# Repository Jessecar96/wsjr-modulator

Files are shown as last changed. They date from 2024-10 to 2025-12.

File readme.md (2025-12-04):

# The Weather STAR Revamped

This project is an update to https://github.com/thetechknight/wsjr-modulator that replaces the Arduino Mega, with a Reaspberry Pi Zero. This allows you to write a data sending solution on device instead of requiring a connection to another computer or server for data.

The `schematic` folder contains the updated schematic and board layout files in KiCad 8. 
`schematic_orig` contains thetechknight's original EAGLE cad schematic.
`code` contains code written for the Arduino based board written for  BASCOM-AVR.

The software that runs on the Raspberry Pi can be found here: https://github.com/Jessecar96/wsjr-data-encoder

License: https://creativecommons.org/licenses/by-nc-sa/4.0/

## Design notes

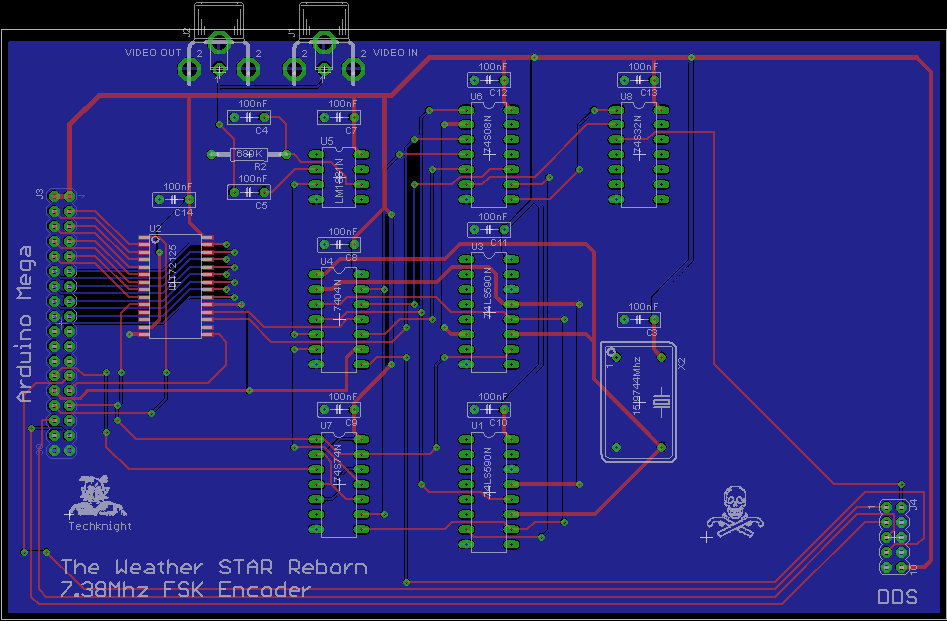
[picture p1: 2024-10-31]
schematic_orig/board.png

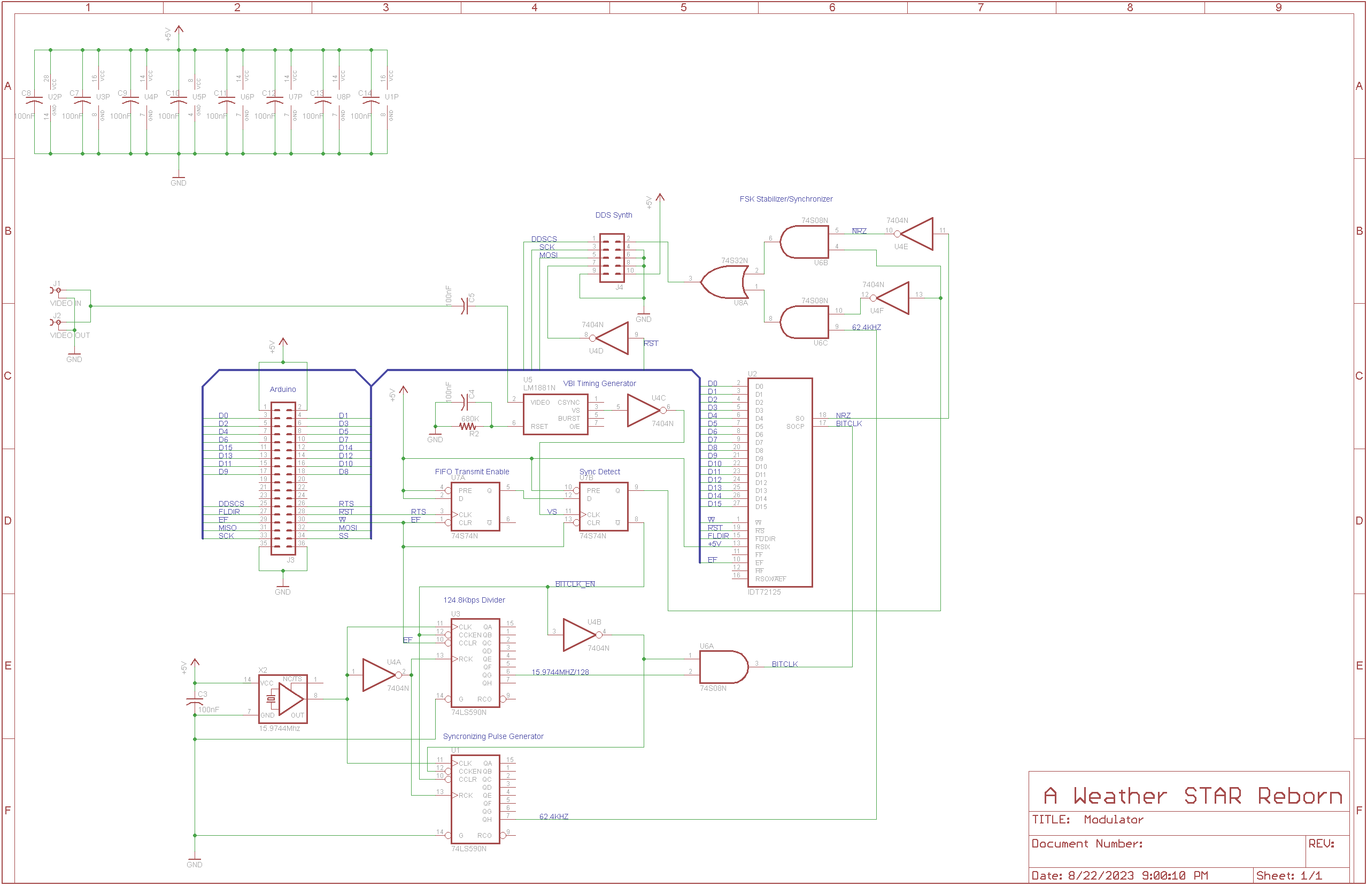
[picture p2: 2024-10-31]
schematic_orig/schematic.png

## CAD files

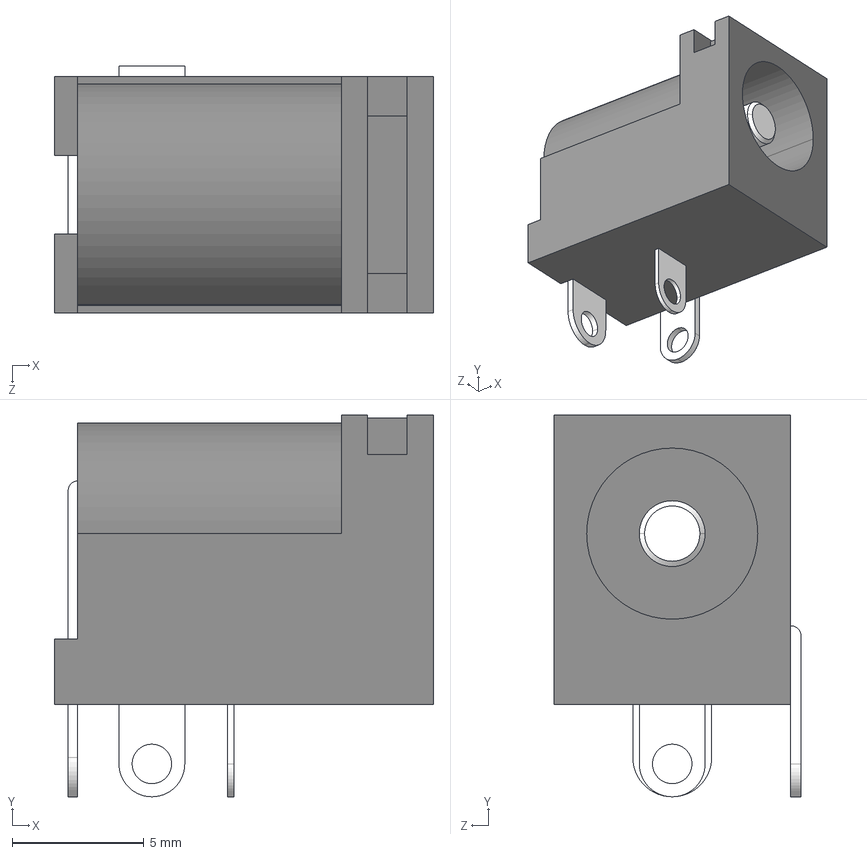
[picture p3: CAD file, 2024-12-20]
schematic/PJ-002B/PJ-002B.step
14.4 x 14.5 x 9.40 mm

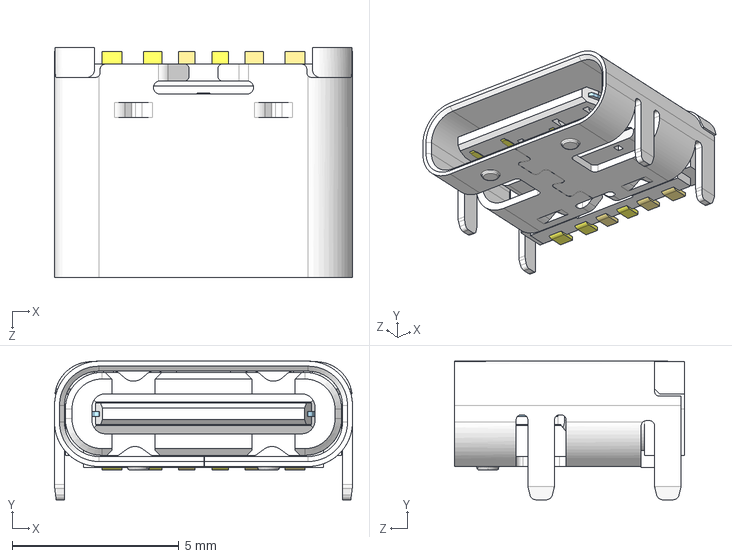
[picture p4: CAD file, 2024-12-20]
schematic/10164359_00011LF/10164359-00011LF.step
8.94 x 4.16 x 6.90 mm

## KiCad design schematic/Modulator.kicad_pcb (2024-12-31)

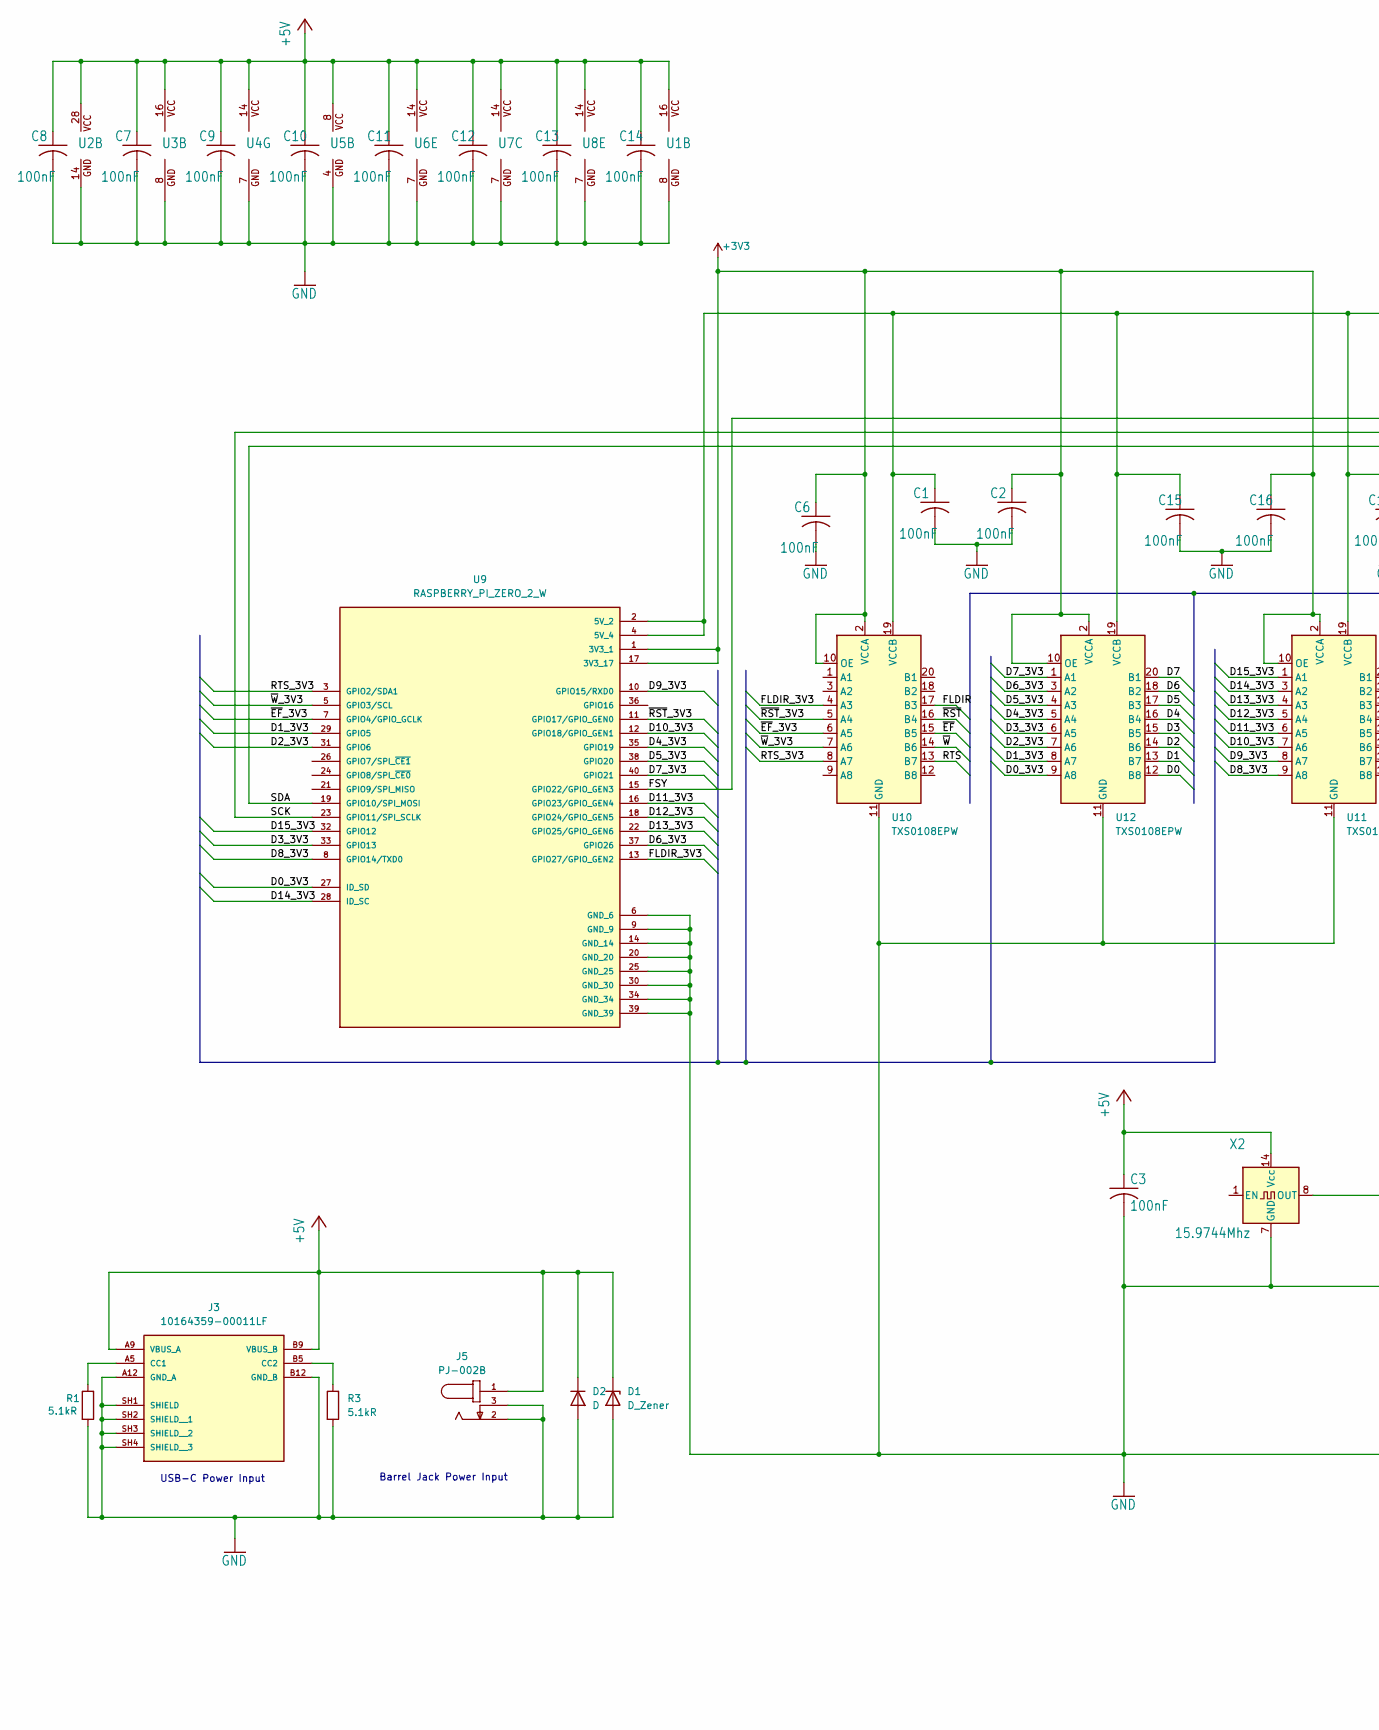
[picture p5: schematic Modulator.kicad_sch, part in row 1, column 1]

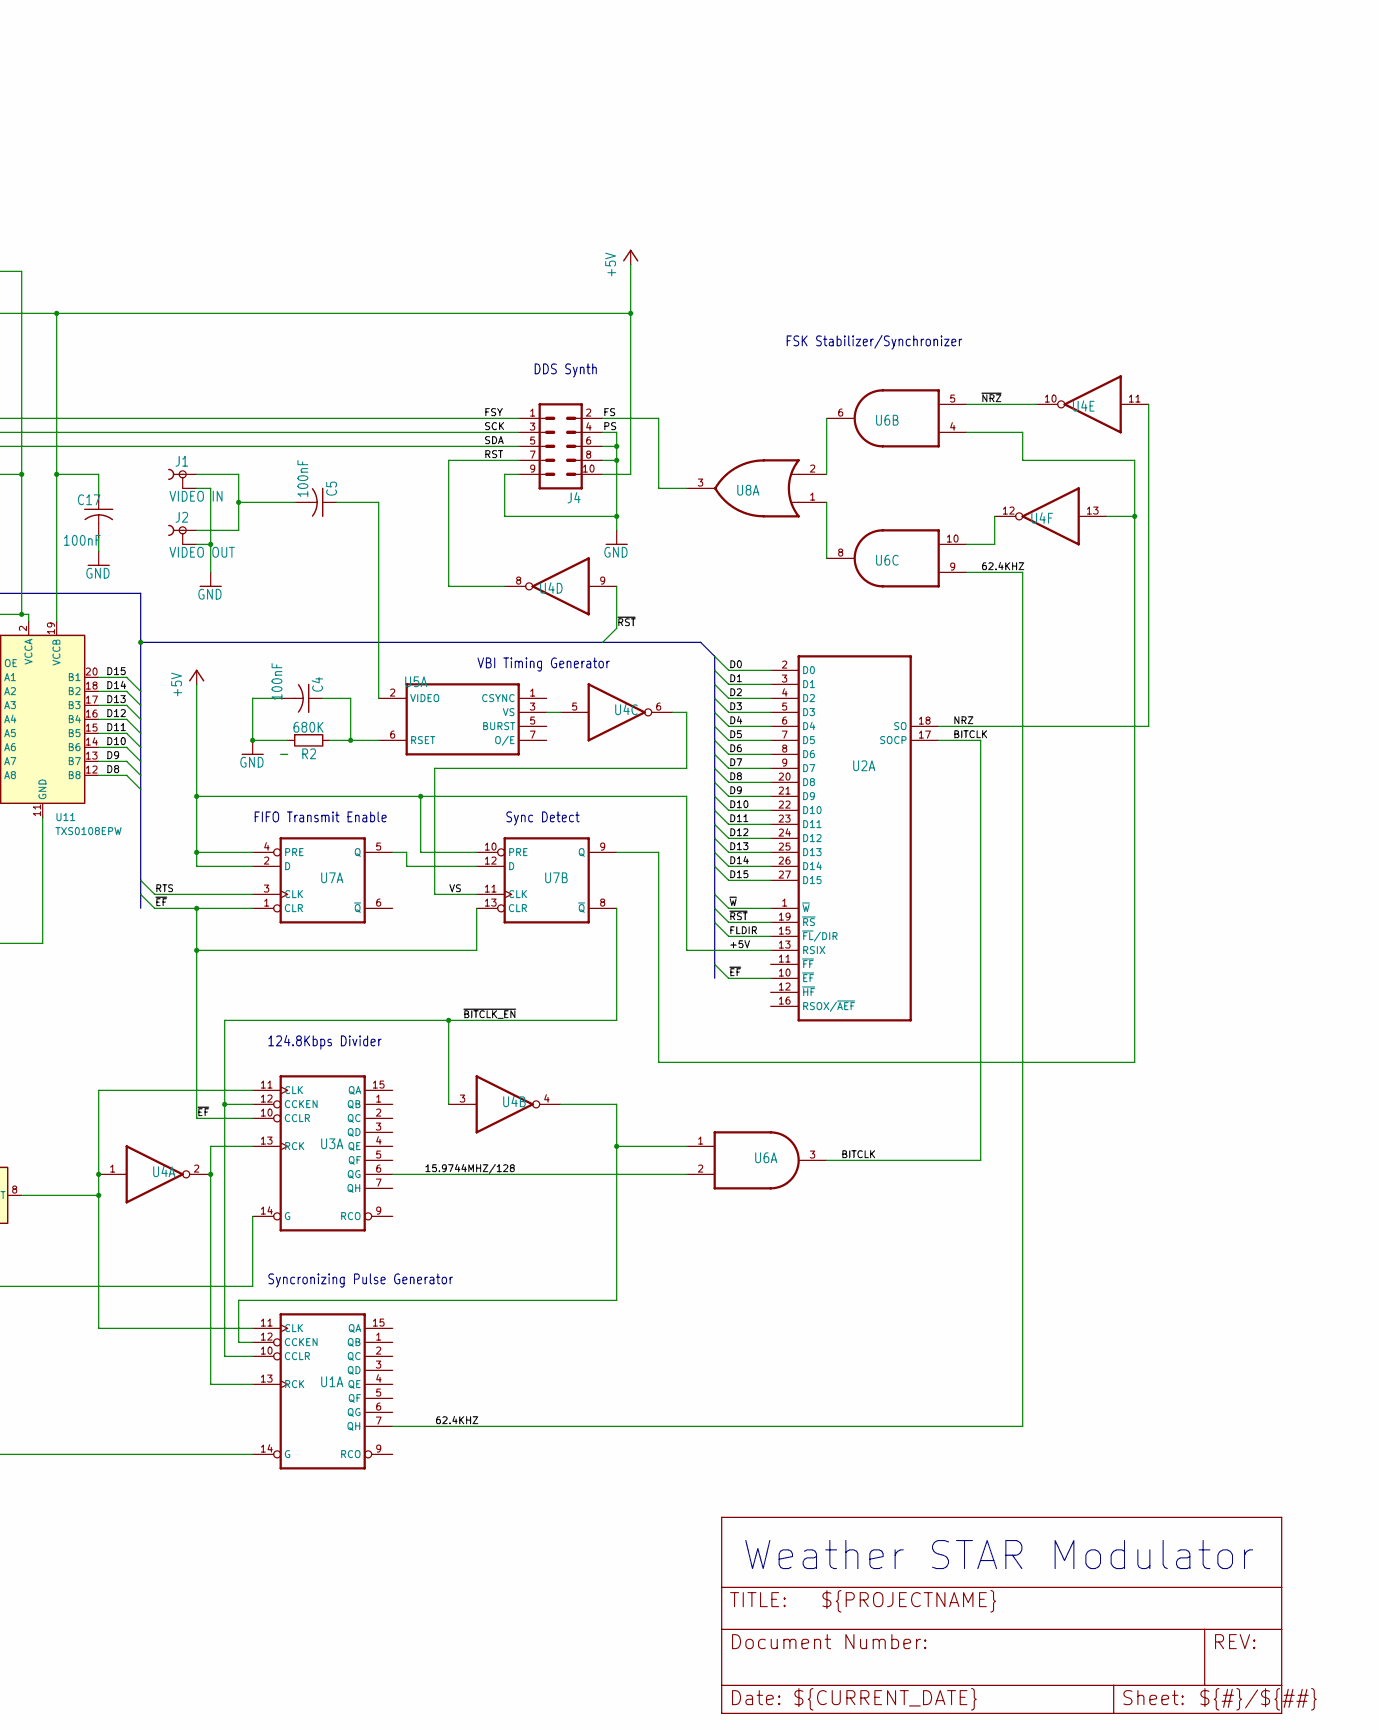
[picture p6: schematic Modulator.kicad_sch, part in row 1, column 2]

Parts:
C1, C2, C6, C15, C16, C17: 100nF; C_0805_2012Metric_Pad1.18x1.45mm_HandSolder
C3, C4, C5, C7, C8, C9, C10, C11, C12, C13, C14: 100nF; C_Disc_D4.7mm_W2.5mm_P5.00mm
D1: D_Zener; D_DO-41_SOD81_P7.62mm_Horizontal
D2: D; D_DO-41_SOD81_P7.62mm_Horizontal
J1: VIDEO IN; TOBU3
J2: VIDEO OUT; TOBU3
J3: 10164359-00011LF; AMPHENOL_10164359-00011LF; PARTREV A
J4: MA05-2; AD9834
J5: PJ-002B; CUI_PJ-002B
R1, R3: 5.1kR; R_0805_2012Metric_Pad1.20x1.40mm_HandSolder
R2: 680K; R_Axial_DIN0207_L6.3mm_D2.5mm_P10.16mm_Horizontal
U1, U3: 74590N; DIL16
U2: IDT72125; DIP-28_W7.62mm_LongPads
U4: 7404N; DIL14
U5: LM1881N; DIL08
U6: 7408N; DIL14
U7: 7474N; DIL14
U8: 7432N; DIL14
U9: RASPBERRY_PI_ZERO_2_W; MODULE_RASPBERRY_PI_ZERO_2_W; PARTREV April 2024
U10, U11, U12: TXS0108EPW; TSSOP-20_4.4x6.5mm_P0.65mm
X2: 15.9744Mhz; Oscillator_DIP-14

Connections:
+3V3: C2.1, C6.1, C16.1, U9.1 (3V3_1), U9.17 (3V3_17), U10.2 (VCCA), U10.10 (OE), U11.2 (VCCA), U11.10 (OE), U12.2 (VCCA), U12.10 (OE)
+5V: C1.1, C3.1, C7.1, C8.1, C9.1, C10.1, C11.1, C12.1, C13.1, C14.1, C15.1, C17.1, D1.1 (K), D2.1 (K), J3.A9 (VBUS_A), J3.B9 (VBUS_B), J4.10, J5.1, U1.16 (VCC), U2.13 (RSIX), U2.28 (VCC), U3.16 (VCC), U4.14 (VCC), U5.8 (VCC), U6.14 (VCC), U7.2 (D), U7.4 (PRE), U7.10 (PRE), U7.14 (VCC), U8.14 (VCC), U9.2 (5V_2), U9.4 (5V_4), U10.19 (VCCB), U11.19 (VCCB), U12.19 (VCCB), X2.14 (Vcc)
/15.9744MHZ/128: U3.6 (QG), U6.2 (I1)
/62.4KHZ: U1.7 (QH), U6.9 (I0)
/BITCLK: U2.17 (SOCP), U6.3 (O)
/D0: U2.2 (D0), U12.12 (B8)
/D0_3V3: U9.27 (ID_SD), U12.9 (A8)
/D1: U2.3 (D1), U12.13 (B7)
/D1_3V3: U9.29 (GPIO5), U12.8 (A7)
/D2: U2.4 (D2), U12.14 (B6)
/D2_3V3: U9.31 (GPIO6), U12.7 (A6)
/D3: U2.5 (D3), U12.15 (B5)
/D3_3V3: U9.33 (GPIO13), U12.6 (A5)
/D4: U2.6 (D4), U12.16 (B4)
/D4_3V3: U9.35 (GPIO19), U12.5 (A4)
/D5: U2.7 (D5), U12.17 (B3)
/D5_3V3: U9.38 (GPIO20), U12.4 (A3)
/D6: U2.8 (D6), U12.18 (B2)
/D6_3V3: U9.37 (GPIO26), U12.3 (A2)
/D7: U2.9 (D7), U12.20 (B1)
/D7_3V3: U9.40 (GPIO21), U12.1 (A1)
/D8: U2.20 (D8), U11.12 (B8)
/D8_3V3: U9.8 (GPIO14/TXD0), U11.9 (A8)
/D9: U2.21 (D9), U11.13 (B7)
/D9_3V3: U9.10 (GPIO15/RXD0), U11.8 (A7)
/D10: U2.22 (D10), U11.14 (B6)
/D10_3V3: U9.12 (GPIO18/GPIO_GEN1), U11.7 (A6)
/D11: U2.23 (D11), U11.15 (B5)
/D11_3V3: U9.16 (GPIO23/GPIO_GEN4), U11.6 (A5)
/D12: U2.24 (D12), U11.16 (B4)
/D12_3V3: U9.18 (GPIO24/GPIO_GEN5), U11.5 (A4)
/D13: U2.25 (D13), U11.17 (B3)
/D13_3V3: U9.22 (GPIO25/GPIO_GEN6), U11.4 (A3)
/D14: U2.26 (D14), U11.18 (B2)
/D14_3V3: U9.28 (ID_SC), U11.3 (A2)
/D15: U2.27 (D15), U11.20 (B1)
/D15_3V3: U9.32 (GPIO12), U11.1 (A1)
/FLDIR: U2.15 (~FL/DIR), U10.17 (B3)
/FLDIR_3V3: U9.13 (GPIO27/GPIO_GEN2), U10.4 (A3)
/FS: J4.2, U8.3 (O)
/FSY: J4.1, U9.15 (GPIO22/GPIO_GEN3)
/NRZ: U2.18 (SO), U4.11 (I)
/RST: J4.7, U4.8 (O)
/RTS: U7.3 (CLK), U10.13 (B7)
/RTS_3V3: U9.3 (GPIO2/SDA1), U10.8 (A7)
/SCK: J4.3, U9.23 (GPIO11/SPI_SCLK)
/SDA: J4.5, U9.19 (GPIO10/SPI_MOSI)
/VS: U4.6 (O), U7.11 (CLK)
/~BITCLK_EN: U1.10 (CCLR), U3.12 (CCKEN), U4.3 (I), U7.8 (~Q)
/~EF: U2.10 (~EF), U3.10 (CCLR), U7.1 (CLR), U7.13 (CLR), U10.15 (B5)
/~EF_3V3: U9.7 (GPIO4/GPIO_GCLK), U10.6 (A5)
/~NRZ: U4.10 (O), U6.5 (I1)
/~RST: U2.19 (~RS), U4.9 (I), U10.16 (B4)
/~RST_3V3: U9.11 (GPIO17/GPIO_GEN0), U10.5 (A4)
/~W: U2.1 (~W), U10.14 (B6)
/~W_3V3: U9.5 (GPIO3/SCL), U10.7 (A6)
GND: C1.2, C2.2, C3.2, C4.2, C6.2, C7.2, C8.2, C9.2, C10.2, C11.2, C12.2, C13.2, C14.2, C15.2, C16.2, C17.2, D1.2 (A), D2.2 (A), J1.2, J1.2@1 (2), J1.2@2 (2), J2.2, J2.2@1 (2), J2.2@2 (2), J3.A12 (GND_A), J3.B12 (GND_B), J3.SH1 (SHIELD), J3.SH2 (SHIELD__1), J3.SH3 (SHIELD__2), J3.SH4 (SHIELD__3), J4.4, J4.6, J4.8, J4.9, J5.2, J5.3, R1.2, R2.2, R3.2, U1.8 (GND), U1.14 (G), U2.14 (GND), U3.8 (GND), U3.14 (G), U4.7 (GND), U5.4 (GND), U6.7 (GND), U7.7 (GND), U8.7 (GND), U9.6 (GND_6), U9.9 (GND_9), U9.14 (GND_14), U9.20 (GND_20), U9.25 (GND_25), U9.30 (GND_30), U9.34 (GND_34), U9.39 (GND_39), U10.11 (GND), U11.11 (GND), U12.11 (GND), X2.7 (GND)
unnamed: C5.2, J1.1, J2.1
unnamed: J3.A5 (CC1), R1.1
unnamed: J3.B5 (CC2), R3.1
unnamed: U1.12 (CCKEN), U4.4 (O), U6.1 (I0)
unnamed: U1.11 (CLK), U3.11 (CLK), U4.1 (I), X2.8 (OUT)
unnamed: U1.13 (RCK), U3.13 (RCK), U4.2 (O)
unnamed: U4.5 (I), U5.3 (VS)
unnamed: U4.13 (I), U6.4 (I0), U7.9 (Q)
unnamed: U4.12 (O), U6.10 (I1)
unnamed: C4.1, R2.1, U5.6 (RSET)
unnamed: C5.1, U5.2 (VIDEO)
unnamed: U6.6 (O), U8.2 (I1)
unnamed: U6.8 (O), U8.1 (I0)
unnamed: U7.5 (Q), U7.12 (D)

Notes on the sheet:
DDS Synth
VBI Timing Generator
USB-C Power Input
FSK Stabilizer/Synchronizer
Weather STAR Modulator
FIFO Transmit Enable
Sync Detect
Barrel Jack Power Input
124.8Kbps Divider
Syncronizing Pulse Generator

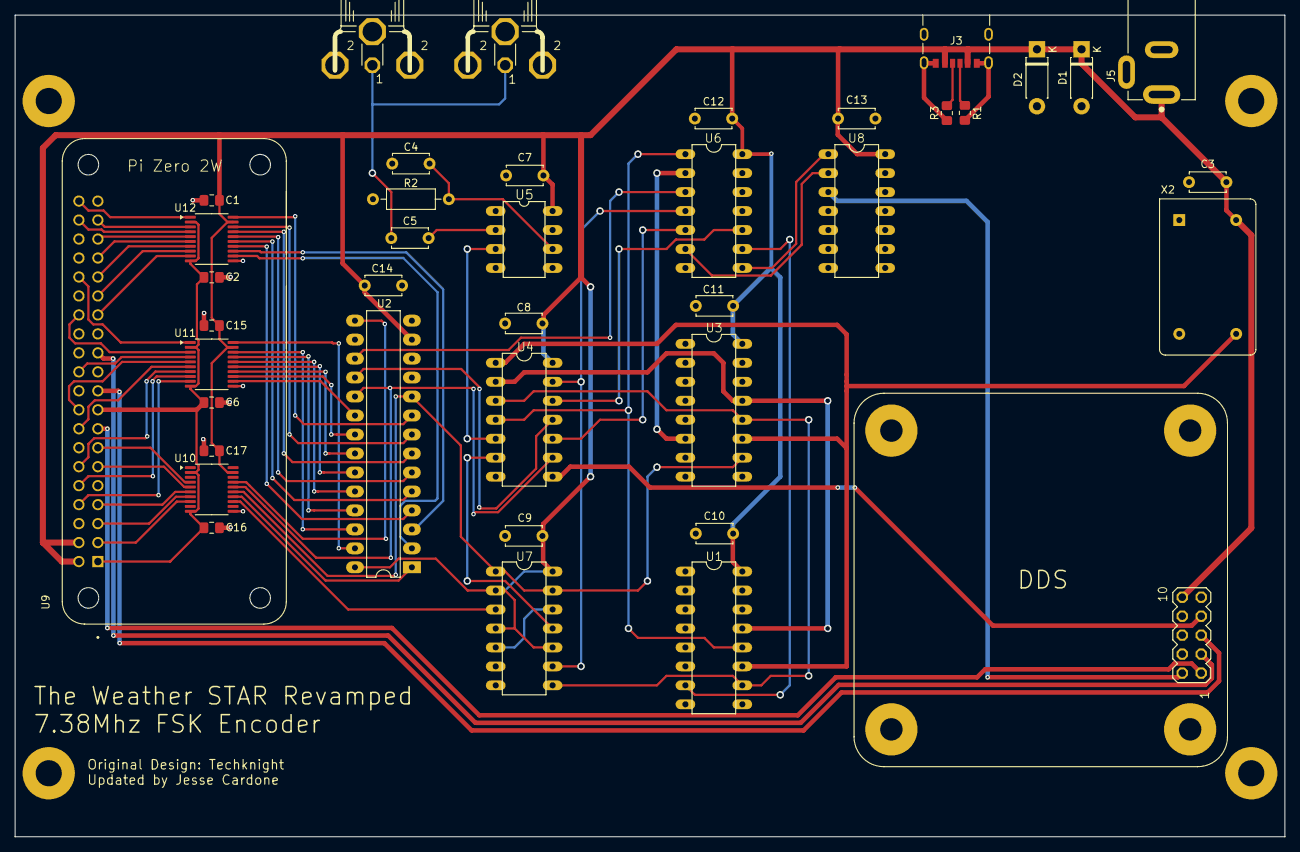
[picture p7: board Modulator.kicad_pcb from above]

Board: 2 copper layers, 170.0 x 110.0 mm, 40 parts (0 on the bottom side), 71 nets.

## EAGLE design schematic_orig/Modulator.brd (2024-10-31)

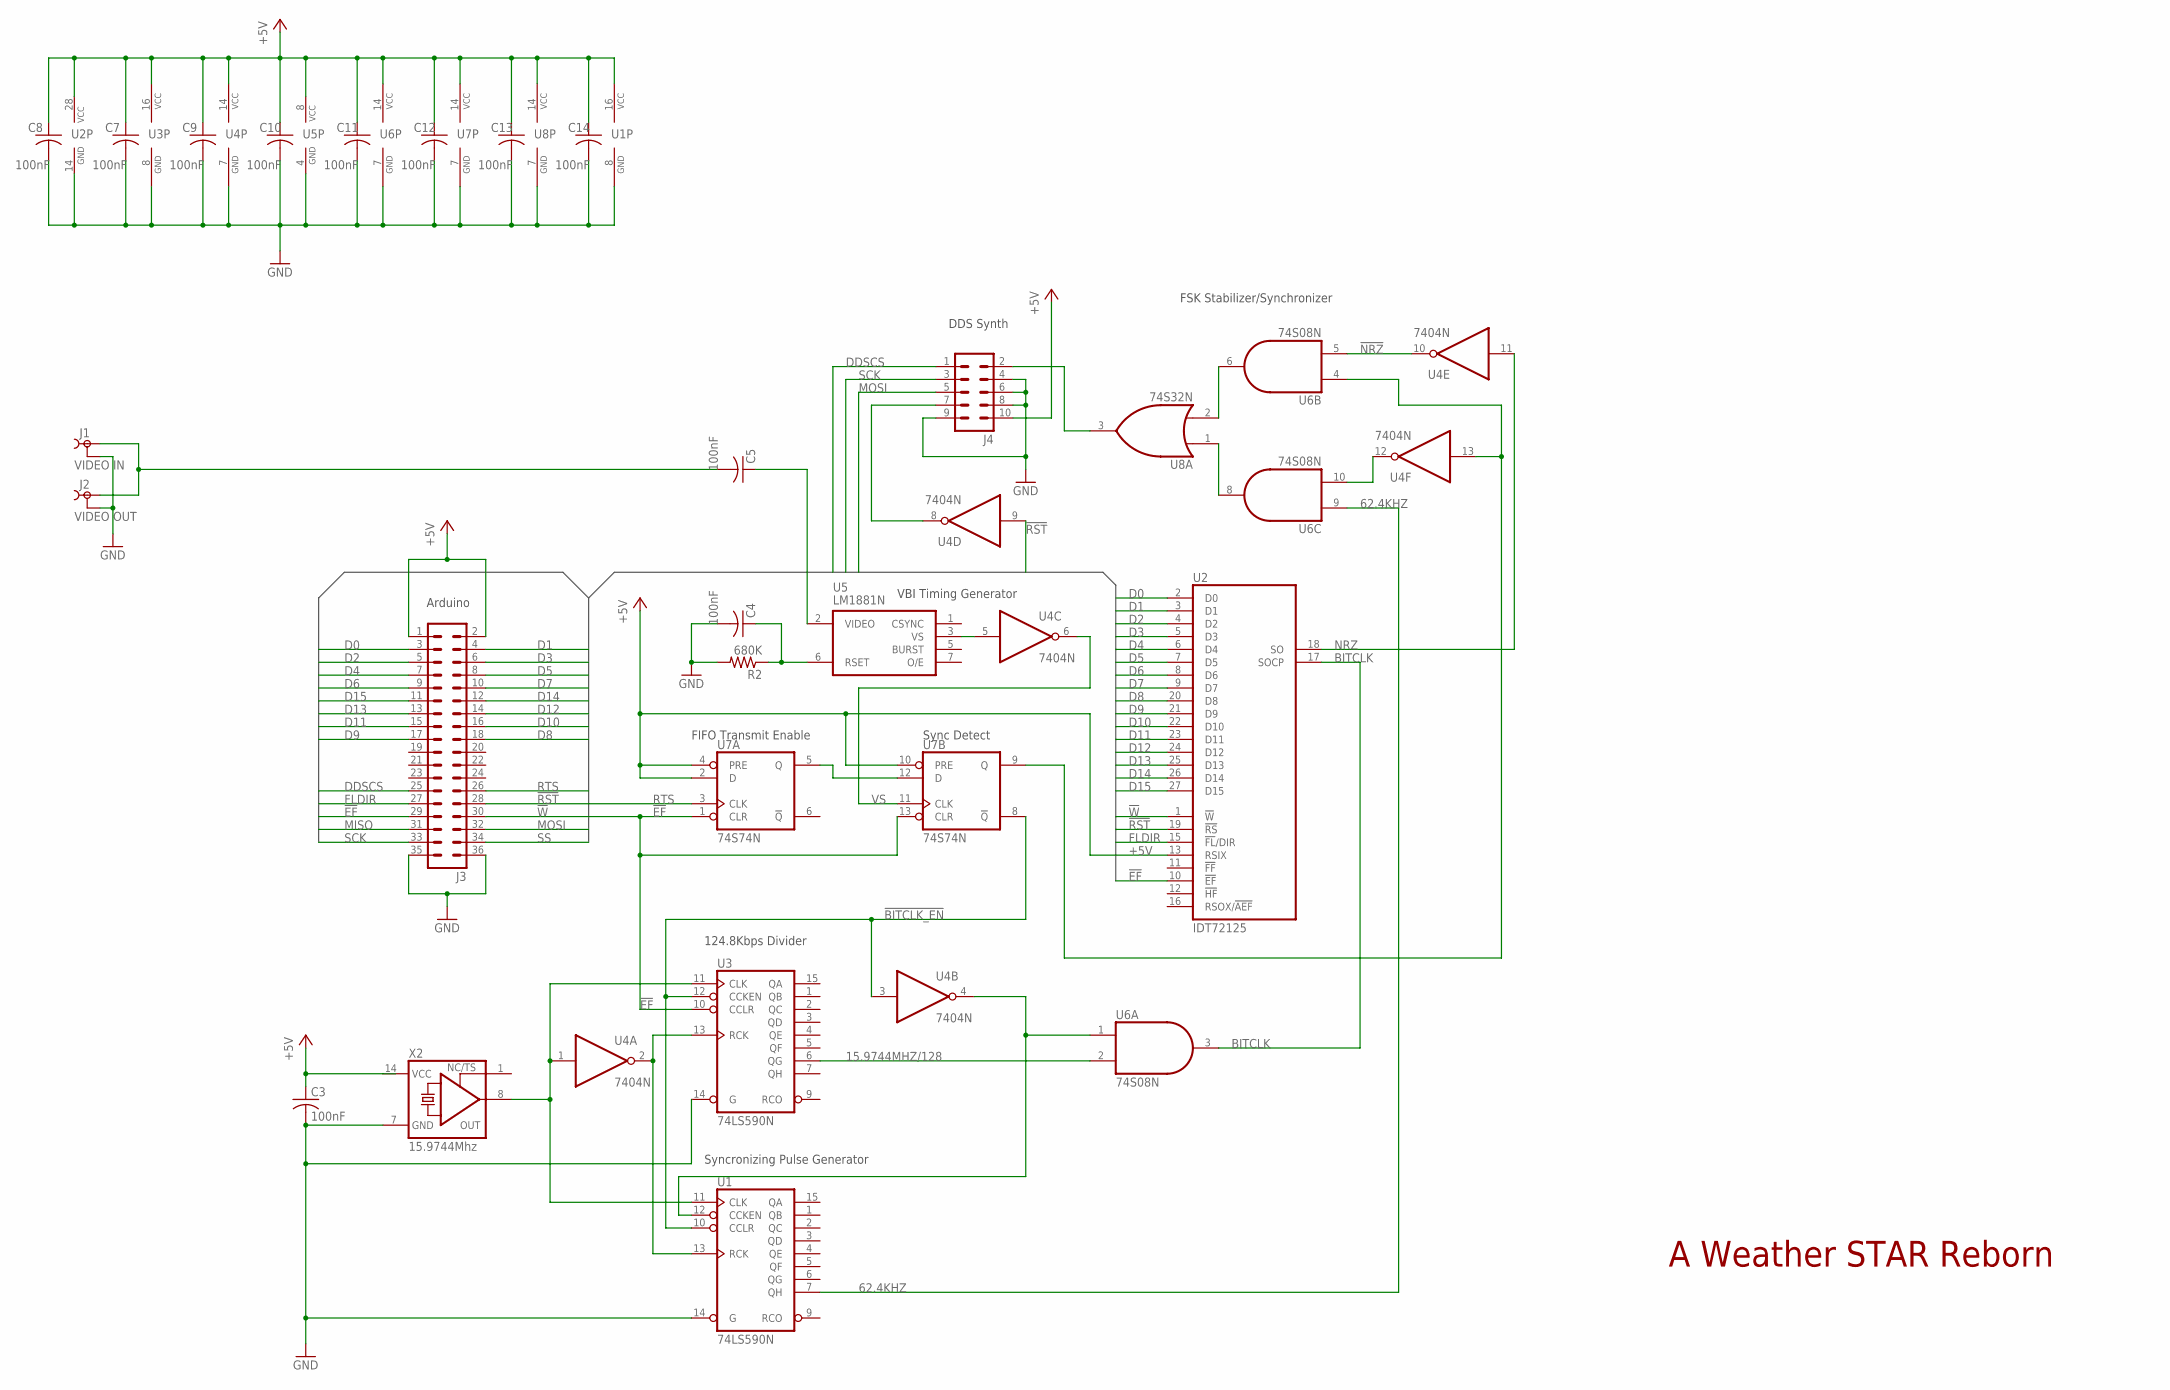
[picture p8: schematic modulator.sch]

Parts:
C3, C4, C5, C7, C8, C9, C10, C11, C12, C13, C14: 100nF; C050-025X075
J1: VIDEO IN; TOBU3
J2: VIDEO OUT; TOBU3
J3: MA18-2
J4: MA05-2
R2: 680K; 0207/12
U1, U3: 74LS590N; DIL16
U2: IDT72125; SO28L
U4: 7404N; DIL14
U5: LM1881N; DIL08
U6: 74S08N; DIL14
U7: 74S74N; DIL14
U8: 74S32N; DIL14
X2: 15.9744Mhz; DIL14S

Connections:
15.9744MHZ/128: U3.6 (QG), U6.2 (I1)
62.4KHZ: U1.7 (QH), U6.9 (I0)
!BITCLK_EN: U1.10 (CCLR), U3.12 (CCKEN), U4.3 (I), U7.8 (!Q)
!EF: J3.29, U2.10 (!EF), U3.10 (CCLR), U7.1 (CLR), U7.13 (CLR)
!NRZ: U4.10 (O), U6.5 (I1)
!RST: J3.28, U2.19 (!RS), U4.9 (I)
!W: J3.30, U2.1 (!W)
+5V: C3.1, C7.1, C8.1, C9.1, C10.1, C11.1, C12.1, C13.1, C14.1, J3.1, J3.2, J4.10, U1.16 (VCC), U2.13 (RSIX), U2.28 (VCC), U3.16 (VCC), U4.14 (VCC), U5.8 (VCC), U6.14 (VCC), U7.2 (D), U7.4 (PRE), U7.10 (PRE), U7.14 (VCC), U8.14 (VCC), X2.14 (VCC)
BITCLK: U2.17 (SOCP), U6.3 (O)
D0: J3.3, U2.2 (D0)
D1: J3.4, U2.3 (D1)
D2: J3.5, U2.4 (D2)
D3: J3.6, U2.5 (D3)
D4: J3.7, U2.6 (D4)
D5: J3.8, U2.7 (D5)
D6: J3.9, U2.8 (D6)
D7: J3.10, U2.9 (D7)
D8: J3.18, U2.20 (D8)
D9: J3.17, U2.21 (D9)
D10: J3.16, U2.22 (D10)
D11: J3.15, U2.23 (D11)
D12: J3.14, U2.24 (D12)
D13: J3.13, U2.25 (D13)
D14: J3.12, U2.26 (D14)
D15: J3.11, U2.27 (D15)
DDSCS: J3.25, J4.1
FLDIR: J3.27, U2.15 (!FL!/DIR)
GND: C3.2, C4.2, C7.2, C8.2, C9.2, C10.2, C11.2, C12.2, C13.2, C14.2, J1.2, J1.2@1 (2), J1.2@2 (2), J2.2, J2.2@1 (2), J2.2@2 (2), J3.35, J3.36, J4.4, J4.6, J4.8, J4.9, R2.2, U1.8 (GND), U1.14 (G), U2.14 (GND), U3.8 (GND), U3.14 (G), U4.7 (GND), U5.4 (GND), U6.7 (GND), U7.7 (GND), U8.7 (GND), X2.7 (GND)
MISO: J3.31
MOSI: J3.32, J4.5
unnamed: J4.7, U4.8 (O)
unnamed: J4.2, U8.3 (O)
unnamed: U1.11 (CLK), U3.11 (CLK), U4.1 (I), X2.8 (OUT)
unnamed: U1.13 (RCK), U3.13 (RCK), U4.2 (O)
unnamed: U1.12 (CCKEN), U4.4 (O), U6.1 (I0)
unnamed: U4.13 (I), U6.4 (I0), U7.9 (Q)
unnamed: C5.2, J1.1, J2.1
unnamed: U7.5 (Q), U7.12 (D)
unnamed: U4.5 (I), U5.3 (VS)
unnamed: U4.12 (O), U6.10 (I1)
unnamed: C4.1, R2.1, U5.6 (RSET)
unnamed: U6.6 (O), U8.2 (I1)
unnamed: C5.1, U5.2 (VIDEO)
unnamed: U6.8 (O), U8.1 (I0)
NRZ: U2.18 (SO), U4.11 (I)
RTS: J3.26, U7.3 (CLK)
SCK: J3.33, J4.3
SS: J3.34
VS: U4.6 (O), U7.11 (CLK)

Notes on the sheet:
A Weather STAR Reborn
124.8Kbps Divider
FIFO Transmit Enable
Sync Detect
VBI Timing Generator
Arduino
DDS Synth
FSK Stabilizer/Synchronizer
Syncronizing Pulse Generator

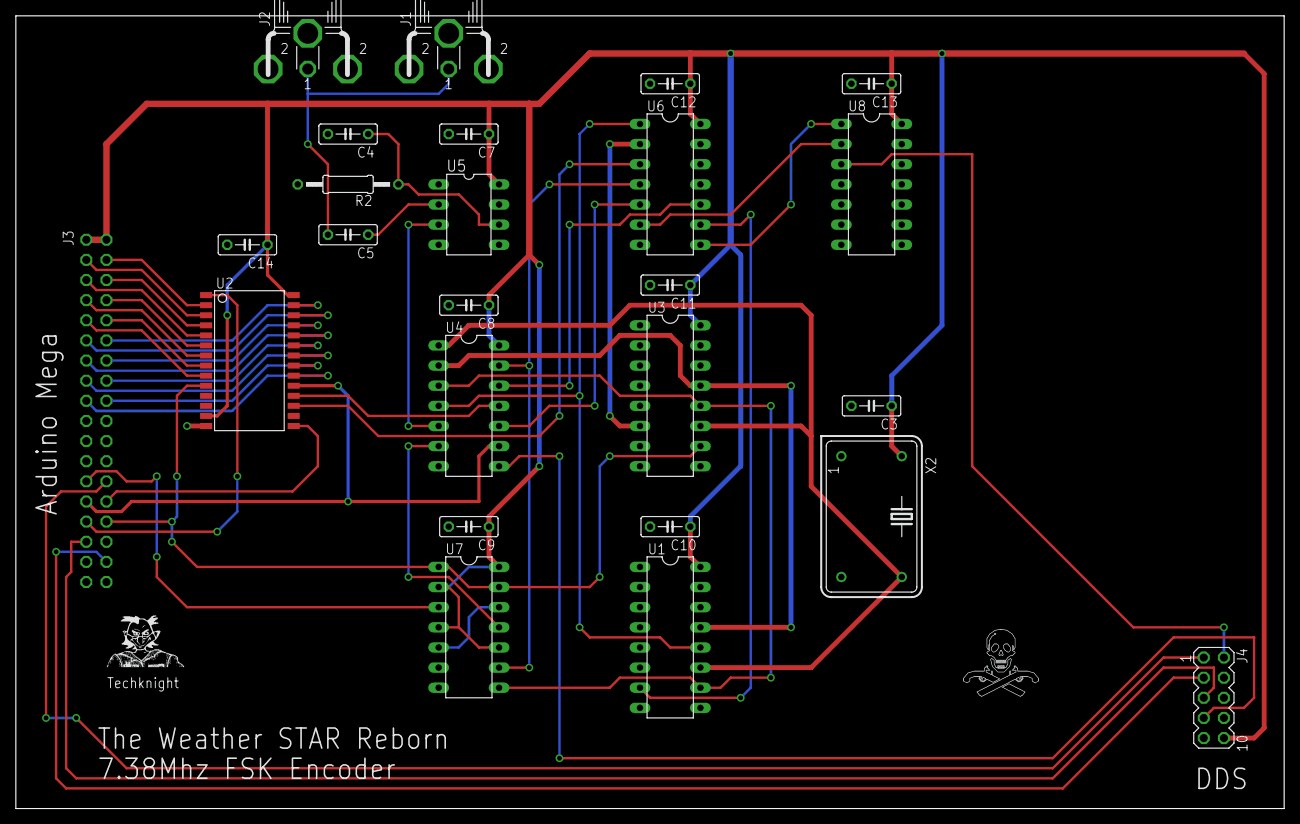
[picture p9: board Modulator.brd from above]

Board: 2 copper layers, 160.0 x 100.0 mm, 27 parts (1 on the bottom side), 47 nets.

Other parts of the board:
U$1: LOGO
U$2: JOLLYROGER

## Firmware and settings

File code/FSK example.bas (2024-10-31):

' *
' * Title         : FSK example.bas
' * Version       : 1.0
' * Target MCU    : ATmega2560
' * Author        : techknight
' * Program code  : BASCOM AVR
' * Hardware req. : Arduino Mega, WeatherSTAR Jr/III
' * Description   : Clocks 37-byte control Packets to the WeatherSTAR Jr
' ***************************************************************************

$regfile = "m2560def.dat"                                   'use ATmega2560 (Mega256 Base System)
$crystal = 16000000                                         '16 Mhz

$hwstack = 128                                              ' default use 32 for the hardware stack
$swstack = 32                                               'default use 10 for the SW stack
$framesize = 64                                             'default use 40 for the frame space

'Define hardware uart on Arduino.
Config Com1 = 115200 , Synchrone = 0 , Parity = None , Stopbits = 1 , Databits = 8 , Clockpol = 0
Config Serialin = Buffered , Size = 254                     ' We are using the hardware UART, in buffered interrupt mode.


'**************************************************************************************************************************
'BEGIN DRIVER DECLARATION
'**************************************************************************************************************************
'Define pins used by the WeatherSTAR Jr. (serial mode)
Readenable Alias Portl.4                                    'RTS in Schematic   (Request to Send signal, Trigger, to transmit the FIFO contents to the receiver)
Writeenable Alias Portl.0                                   '/W In Schematic    (Write strobe to insert 16-bits of data into the FIFO)
Empty Alias Pinl.1                                          '/EF in Schematic   (Signal to indicate the FIFO is empty and ready for a new frame)
Periphreset Alias Portl.2                                   '/RST in Schematic (Resets both the FIFO, and DDS chip into initial states)
Direction Alias Portl.3                                     'FLDIR in Schematic (FIFO when in reset mode reads this for cascading, or MSB/LSB indication for data direction)
Ddsenable Alias Portl.5                                     'DDSCS in Schematic (FSync on DDS chip, used to select the chip when the SPI is communicating with it)

Fifolow Alias Porta                                         'Low 8-bits for FIFO Data
Fifohigh Alias Portc                                        'High 8-bits for FIFO Data

Config Portl.1 = Input
Config Fifolow = Output
Config Fifohigh = Output
Config Readenable = Output
Config Writeenable = Output
Config Empty = Input
Config Periphreset = Output
Config Direction = Output
Config Ddsenable = Output
Config Portb.0 = Output                                     'Compensate for the SS line (not used, but has to be driven high or the AVR will get stuck in slave-only mode, Painful experience)

'Setup the port pins for the initial state.
Reset Readenable                                            'reading not allowed
Reset Writeenable                                           'write not allowed
Set Periphreset                                             'Hold the DDS, and the FIFO into RESET mode until we are ready.
Reset Direction                                             'Sets our chip in to single mode.
Set Ddsenable                                               'Make sure we do not have our IC selected
Fifolow = 0
Fifohigh = 0

'Setup the SPI for the AD9834 DDS Baud Clock Generator.
Set Portb.0                                                 'Set SS High (Not used, must be high to stay in master mode)
Config Spi = Hard , Interrupt = Off , Data_order = Msb , Master = Yes , Polarity = High , Phase = 0 , Clockrate = 4 , Noss = 1
Spiinit                                                     'Initialize the SPI hardware
Set Ddsenable                                               'Make sure our DDS select state is maintained

'Declare Variables used in the driver process
Dim Dataframe(38) As Byte                                   'Array used to build and send the 37 byte Teletext Data.
Dim Dataframe2(38) As Byte                                  'Array used to build and send the 37 byte Teletext Data.
Dim Dataframe3(38) As Byte                                  'Array used to build and send the 37 byte Teletext Data.
Dim Ddsword(2) As Byte                                      '16 bit array for DDS values.
Dim I As Byte                                               'Index counter to keep track of loops.
Dim Iv As Long                                              'Contains the 21-bits of data for the XOR encipher routine
Dim Shiftivcount As Byte                                    'Contains the count value of each logical shift of the IV Register


'Declare Subroutines for the required operation.
Declare Function Gethammingcode(byval Databyte As Byte) As Byte
Declare Function Calculateparity(byval Character As Byte) As Byte
Declare Function Encryptbyte(byval Databyte As Byte) As Byte
Declare Sub Initperipherals()
Declare Sub Setfrequency(byval Frequency As Long)


'**************************************************************************************************************************
'END DRIVER DECLARATION
'**************************************************************************************************************************

Disable Interrupts
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

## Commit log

2024-10-31 Add board layout
    [Modulator.brd]
2024-12-17 First draft of new circuit with raspberry pi
    [Modulator.brd, Modulator.kicad_pcb, Modulator.kicad_sch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]
2024-12-17 Fix ground on top of bus
    [Modulator.kicad_sch]
2024-12-20 First draft of PCB routing
    [10164359-00011LF.step, Modulator.kicad_pcb, Modulator.kicad_sch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]
2024-12-20 Make room for SMA connectors on DDS board
    [Modulator.kicad_pcb, Modulator.kicad_sch]
2024-12-21 Add decoupling capacitors to level shifters
    [Modulator.kicad_pcb, Modulator.kicad_sch]
2024-12-22 Change some decoupling capacitors, and usb-c resistors to SMT
    [Modulator.kicad_pcb, Modulator.kicad_sch]
2024-12-22 Update capacitor footprints
    [Modulator.kicad_pcb, Modulator.kicad_sch]
2024-12-22 Slight cleanup
    [Modulator.kicad_pcb]
2024-12-23 Add holes for case
    [Modulator.kicad_pcb]
2024-12-31 Update label placement
    [Modulator.kicad_pcb]
2024-12-31 Fix another label placement
    [Modulator.kicad_pcb]
